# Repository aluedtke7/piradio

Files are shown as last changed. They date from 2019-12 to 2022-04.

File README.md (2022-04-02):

## Internet radio player for the Raspberry PI written in GO

This project describes what is neccessary to build an internet radio player with GO for the Raspberry Pi.
There is a [documentation file](doc/development.md) about some aspects of the software design
(i.e. _why do you use an extra channel for the display?_).

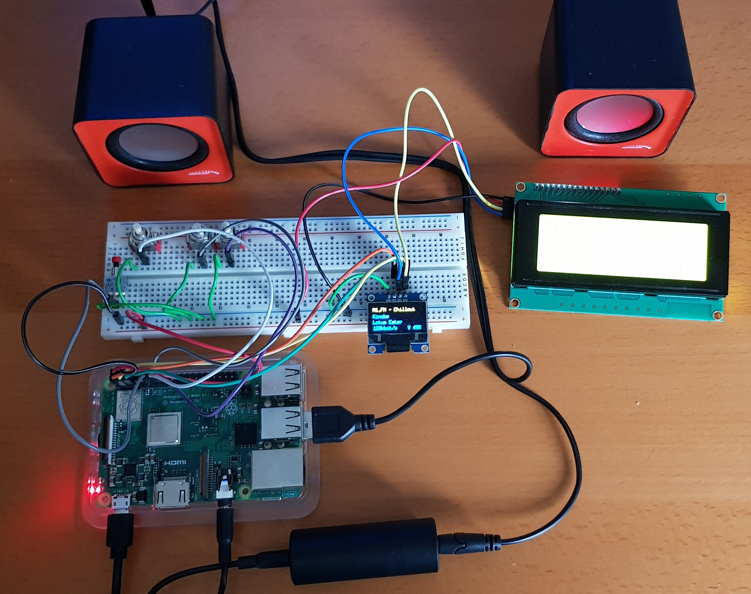
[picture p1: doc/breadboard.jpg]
breadboard


The wiring is also documented with a fritzing sketch.
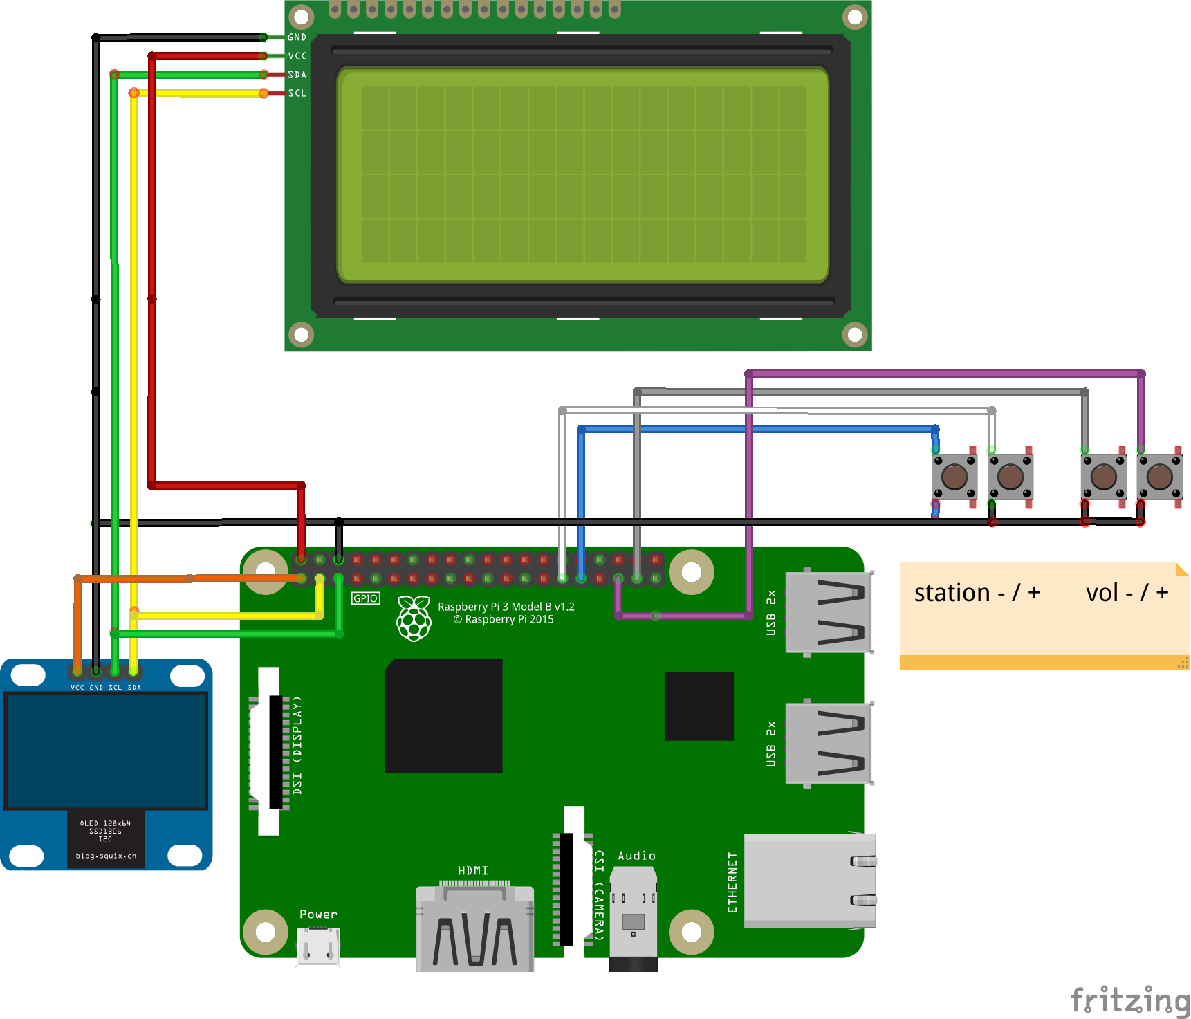
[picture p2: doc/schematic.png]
Fritzing


### Hardware

For the development I'm using a model 3B+ but the final target will be a Raspberry PI Zero WH.
This is the cheapest model that has WIFI. An internet radio without WIFI doesn't makes sense
in my opinion.

The documentation about that version can be found [here](doc/raspi_zero.md).

#### Displays

As display you can choose between two differnt types: a 20x4 LCD or a 0,96" OLED both with i²c interface. The program
can handle both of them but not simultaneously. There's a flag to switch between LCD and OLED (hint try `piradio -help`).

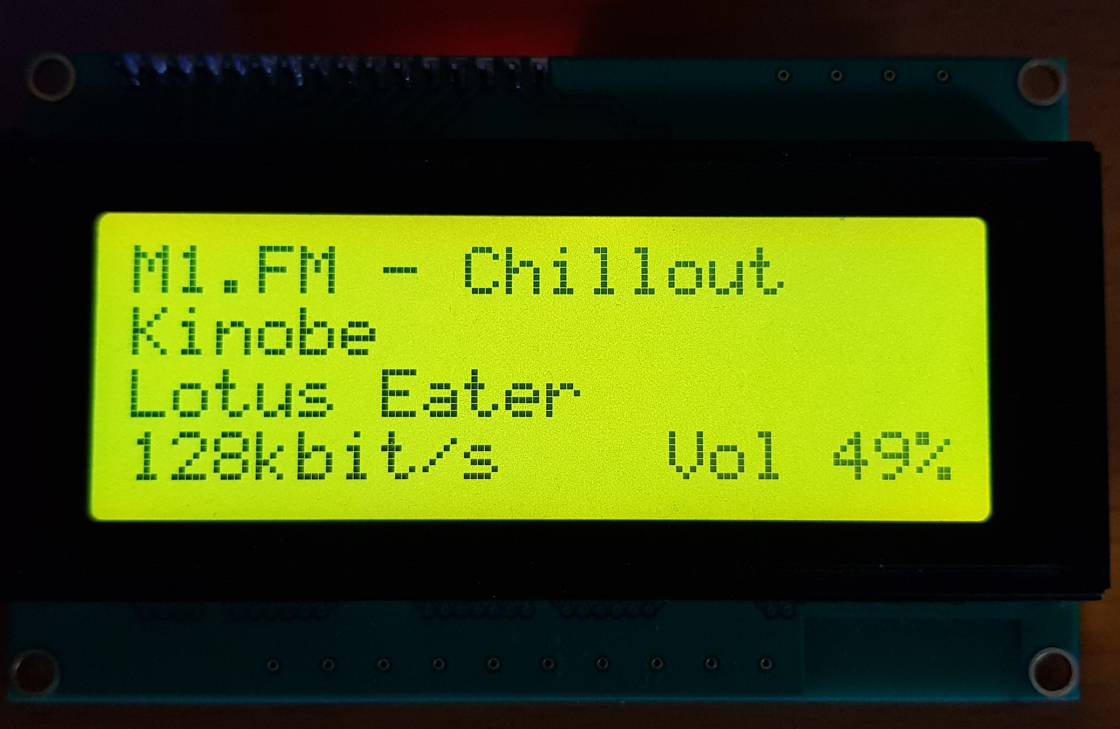
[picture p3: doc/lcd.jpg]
LCD


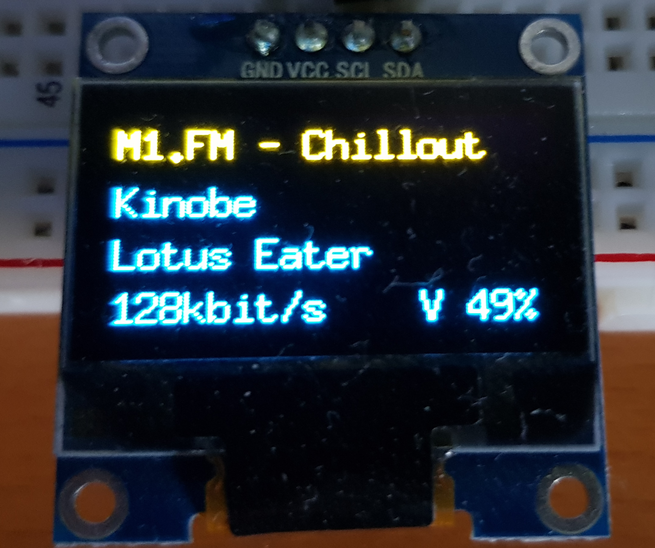
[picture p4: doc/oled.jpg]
OLED


#### Speaker

It's up to you what you use as loudspeakers. I'm using a pair of cheap usb speakers. It's absolutely neccessary to
have a galvanic isolation between the loudspeaker input and the raspberry pi. Otherwise you will hear any possible
interferences in the speakers. I bought the noise filter (ground loop isolator, the black round tube at the bottom of
the photo) from a big american online warehouse.

It's also possible to connect a Bluetooth speaker to the raspberry pi, but that
is documented in the [readme of the Raspi Zero W](doc/raspi_zero.md).

### Software

The software is written in GO (1.18) and it uses the `mplayer` for the heavy lifting part (music streaming etc.).
There are currently 5 (self describing) buttons:

- next station
- previous station
- increase volume
- decrease volume
- mute/unmute

The list of stations is loaded at the start from the location `~/.piradio/stations`. If this file doesn't exist or is
empty, a default list with 3 stations is created. This part was inspired by the
[goradio](https://github.com/jcheng8/goradio) project.

The last played station will be remembered. The actual list index is stored in
`~/.piradio/last_station`. On the next start, the last used station index is loaded. When a station
change is made, the actual index is delayed written to the file (see `debounceWrite`).

The software will always use a 4 line layout on both displays. The LCD can show 20 characters per line and the OLED
is able to show 18,5 characters.
The first line shows always the station name. The second line will display the artist and the title is in the third line.
These two lines automatically scroll in case of long strings. The scroll speed is configurable via flag
`-scrollSpeed`. It's also possible to scroll the station name, but that has to be enabled via flag `-scrollStation`.

The fourth line shows the stream bitrate and the volume level. When the station is changed, the current time and date is
displayed while the next station is loaded. When the first station in the list is selected, the ip address is displayed
instead.

### Preparation of the Raspberry PI

The following paragraphs imply that your raspberry pi is already configured with raspbian and set up in a way that
you can ping him (at 10.7.7.43 in my case) from another pc.

#### enable ssh for login

In file `/etc/ssh/sshd_config` on the raspberry pi change/add the line

    PermitRootLogin yes

Save the file (you probably should use `sudo` for this). After that execute the next two lines

    sudo systemctl start ssh
    sudo systemctl enable ssh

Then execute on the pc

    ssh-copy-id -i ~/.ssh/id_rsa.pub pi@10.7.7.43

This will ensure that you don't need a password for connecting.

On the raspberry pi enter

    sudo passwd

to set a new password for user **root**. After that, enter the following line on the pc:

    ssh-copy-id -i ~/.ssh/id_rsa.pub root@10.7.7.43

This way, you also don't need a password when connecting as user root.

#### Enable i²c

Start program `sudo raspi-config` and select menu `5 Interfacing Options` and there the sub menu
`P5 i²c` via cursors and press ENTER. Move to `<YES>` via cursor keys and press ENTER again.

Restart now the raspberry via `sudo reboot`.
Login and test via tool `i2cdetect` the i²c bus:

    sudo i2cdetect -y 1     # or ...-y 0

This is the output when both displays are connected (LCD is at 27 and OLED is at 3c):

         0  1  2  3  4  5  6  7  8  9  a  b  c  d  e  f
    00:          -- -- -- -- -- -- -- -- -- -- -- -- --
    10: -- -- -- -- -- -- -- -- -- -- -- -- -- -- -- --
    20: -- -- -- -- -- -- -- 27 -- -- -- -- -- -- -- --
    30: -- -- -- -- -- -- -- -- -- -- -- -- 3c -- -- --
    40: -- -- -- -- -- -- -- -- -- -- -- -- -- -- -- --
    50: -- -- -- -- -- -- -- -- -- -- -- -- -- -- -- --
    60: -- -- -- -- -- -- -- -- -- -- -- -- -- -- -- --
    70: -- -- -- -- -- -- -- --

In case the tool is not installed:

    sudo apt update && sudo apt install i2c-tools

#### Start binary with parameters

Piradio comes with several command line parameters. When no parameters are given, the LCD will be used.
All parameters are case sensitive.

    cd /home/pi
    ./piradio           # uses the LCD
    ./piradio -oled     # uses the OLED
    ./piradio -help     # shows all options
    Usage of ./piradio:
      -backlightOff
        	set to switch off backlight after some time
      -backlightOffTime int
        	backlight switch off time in s (3s...3600s) (default 15)
      -camelCase
        	set to format title
      -debug
        	set to output mplayer info on stdout
      -lcdDelay int
        	initial delay for LCD in s (1s...10s) (default 3)
      -noBluetooth
        	set to only use analog output
      -noise
            set to remove noise from title
      -oled
        	set to use OLED Display
      -scrollSpeed int
        	scroll speed in ms (100ms...10000ms) (default 500)
      -scrollStation
        	set to scroll station names

Description of the options:

- backlightOff: if set and if using the LCD, the backlight will be switched off after NN seconds, when no button
  is pressed during this time.
- backlightOffTime: the time in seconds the backlight is on. Will be reset with every button press.
- camelCase: if set, the Title will be formatted in a _camel case_ way
- debug: in case of problems set this option a see what happens on the comand line. `piradio` has to
  be started manually in the shell to see the output.
- lcdDelay: sometimes the LCD will not be correctly initialized and the display shows funny characters.
  In this case increase this value. Only needed for the LCD.
- noBluetooth: when set, no bluetooth connection will be tried.
- noise: some stations transmit very long title names with the remix name in round brackets. If you
  enable this option these strings will be removed and the title will most probably fit on the display without
  scrolling.
- oled: set this option to use the OLED display.
- scrollSpeed: the scrolling is set by default to a speed of 500ms. If this speed is too fast or too
  slow for you, please set a different value here.
- scrollStation: if you want the station name to scroll in case of long names, please enable
  this option.

Various options set:

    ./piradio -oled -camelCase -scrollStation -scrollSpeed=300
    ./piradio -camelCase=false -debug=false -scrollSpeed=300 -scrollStation=false -oled=true
    ./piradio -camelCase=false -debug=false -scrollSpeed=750 -scrollStation=false -lcdDelay=5 -noise=true

### Start piradio on boot

#### Start

In order to start piradio on every boot, we have to add a line in `/etc/rc.local`:

     su pi -c '/home/pi/piradio -oled -scrollSpeed=300 &'

Please put this line **before** the line containing `exit 0`!

This will start `piradio` as a background task of user `pi`. The user switch is needed because otherwise
`piradio` would run with `root` priviliges.

The parameter used are just one possibility to start `piradio` and can also be omitted. It's important
to end the line with an `&` and that the user has the right to start `piradio` in that folder.
The file `rc.local` needs admin rights to be changed:

    sudo nano /etc/rc.local

#### Stop

If you need to stop the automatically started `piradio`, please proceed as follows. First, get the
`Process Group ID (PGID)` of piradio and the mplayer processes:

    ps -o pgid,cmd -U pi

    PGID  CMD
     561  /lib/systemd/systemd --user
     561  (sd-pam)
     570  /home/pi/piradio -oled -scrollSpeed=300
     570  mplayer -quiet http://tuner.m1.fm/chillout.mp3
     570  mplayer -quiet http://tuner.m1.fm/chillout.mp3
     981  sshd: pi@pts/0
     993  -bash
    1044  ps -o pid,ppid,pgid,cmd -U pi

The line containing `/home/pi/piradio ...` has a number (570) in column `PGID`. This PGID number is also
shown in the lines containing `mplayer ...`. To stop all these processes in one go, enter the following:

    kill -- -570

Now you can copy your fresh version of `piradio` to your Raspberry Pi.

### See title/interpret in terminal

If you want to see the actual title/interpret in a remote terminal, you should
run the following command to see the log of piradio:

    less ~/.piradio/log/piradio.pi.INFO

Press `<shift>+<f>` to let less update the log constantly.

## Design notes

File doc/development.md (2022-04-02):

## Development
#### Cross compilation
On your development machine run the following line to build a `piradio` binary that can run on a
raspberry pi:

    GOOS=linux GOARCH=arm go build -o piradio -v piradio.go
    
This will create a binary named `piradio` that can run on an ARM processor running linux.

#### Copy binary to raspberry
If your ssh key is present on the raspberry, you don't need credentials to copy the binary:

    scp piradio pi@10.7.7.43:

or both commands in one go:

    GOOS=linux GOARCH=arm go build -o piradio -v piradio.go && scp piradio pi@10.7.7.43:

#### Run tests
Normally you're developing on a pc. Therefore, the tests will also run on this pc and you have to start
the tests as follows:

    go test piradio.go piradio_test.go -v

Please keep in mind, that you can't test the special raspberry functionalities (GPIO, I²C etc.). 
This can only be tested, if you run them on a raspberry pi with installed GO. See next chapter.

The current tests don't need a raspberry pi and will run on the dev machine without problems.

#### Update all Modules
Run the following command to update all libraries/modules:

    go get -u

#### Install GO on the raspberry
If you don't like cross compilation or if you want to run tests that needs a raspberry pi, you can install
GO directly on the raspberry. Get the golang tar archive from Google:

    curl -L https://dl.google.com/go/go1.13.linux-armv6l.tar.gz -o go1.13.linux-armv6l.tar.gz

Extract the archive:

    sudo tar -C /usr/local -xvf go1.13.linux-armv6l.tar.gz

Test the golang installation:

    go version

## Some thoughts

#### Why a command channel for the display?
The LCD and the OLED package each have a channel that must be used to send data and commands via i²c to the 
display. If we wouldn't use this approach, the commands and data would get mixed up when more than one line 
should display scrolling text. This could lead to a display that doesn't react anymore.

#### Why don't you use WaitForEdge() on the GPIO pins?
This was indeed my first attempt. With that implementation I needed a minimum debounce time of 250ms in order to work 
halfway. Even with this high debounce time I had several double button clicks when I switched through the
stations.

The final implementation works as desired and has a low debounce time of 100ms.

#### Missing artist and/or title
Most probably this behaviour is caused by the radio station. If you are in doubt, please switch the debug mode (-debug) 
on and see for yourself. The output of the mplayer is printed to stdout. The artist/title
information is found in the ICY Info StreamTitle field.
Usually, this field contains the artist and title separated by a hyphen.

Sometimes the StreamTitle field is transported but it's empty.

The other displayed parts (station name and bitrate) might also not be available.
The station name e.g. is transported in the Name field of the stream.

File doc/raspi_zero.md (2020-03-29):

## Preparing the Raspberry Zero W

### Create Micro-SD card
Download the Raspbian Buster Lite image from [this site](https://www.raspberrypi.org/downloads/raspbian/).
Unzip the downloaded file and insert an empty sd card into the card reader.
Check which device is responsible for this card:

    lsblk -p
    
This will give a list with a lot of devices. In my case, the last line showed

    /dev/sdc      8:32   1   3,7G  0 disk

This is the 4GB sd card I'm using. Now enter the following command to copy the image 
to the sd card:

    sudo dd bs=4M if=2019-09-26-raspbian-buster-lite.img of=/dev/sdc status=progress conv=fsync
    
This will take some time. In my case it took 226 seconds. Run `sync` in order to flush
all cached data to the sd card.

### First Boot
Insert the sd card in the sd card slot of the zero w. Connect a display and a keyboard
via the HDMI mini and USB micro connectors and connect the power via the second (right most) 
micro USB connector.

When the login prompt appears, login as user *pi* with password *raspberry* (please mind the English 
keyboard layout).

Run `raspi-config` and select the correct locale, timezone, keyboard layout and wifi country from
menu **4** (Localisation Options). When entering the locale, please select all locales for your country: for German this 
is `de_DE, de_DE.UTF-8 and de_DE@euro`. In menu **2** (Network Options) enter a name for your raspberry.

In order to **not** store the wifi passwords in a human readable way, please proceed as follows
for all wifi networks:

    wpa_passphrase SSID-OF-WIFI SECRET-PASSWORD >> /etc/wpa_supplicant/wpa_supplicant.conf

This tool will add the network settings of the wifi at the end of the given file. Please run

     sudo nano /etc/wpa_supplicant/wpa_supplicant.conf
     
and check the generated part. Remove the commented lines with the unencrypted passwords.

Reboot, login again and try to ping your router.

### Enabling ssh connections and i²c 
Run `raspi-config` and enable *ssh* and *i²c* from menu **5** (Interfacing Options).

Now you can access your Zero W from other computer via `ssh pi@10.7.7.39` i.e. If you want to connect
without entering a password, you have to give your public ssh key to the raspi:

     ssh-copy-id pi@10.7.7.39
     
After done that, you can ssh into your raspi without entering a password.

### Install mplayer
Run `sudo apt update && sudo apt install mplayer`.

#### Enable i²c
Start program `sudo raspi-config` and select menu `5 Interfacing Options` and there the sub menu
`P5 i²c` via cursors and press ENTER. Move to `<YES>` via cursor keys and press ENTER again.

Restart now the raspberry via `sudo reboot`.
Login and test via tool `i2cdetect` the i²c bus:

    sudo i2cdetect -y 1     # or ...-y 0
    
This is the output when both displays are connected (LCD is at 27 and OLED is at 3c):

         0  1  2  3  4  5  6  7  8  9  a  b  c  d  e  f
    00:          -- -- -- -- -- -- -- -- -- -- -- -- -- 
    10: -- -- -- -- -- -- -- -- -- -- -- -- -- -- -- -- 
    20: -- -- -- -- -- -- -- 27 -- -- -- -- -- -- -- -- 
    30: -- -- -- -- -- -- -- -- -- -- -- -- 3c -- -- -- 
    40: -- -- -- -- -- -- -- -- -- -- -- -- -- -- -- -- 
    50: -- -- -- -- -- -- -- -- -- -- -- -- -- -- -- -- 
    60: -- -- -- -- -- -- -- -- -- -- -- -- -- -- -- -- 
    70: -- -- -- -- -- -- -- --                         

In case the tool is not installed:

    sudo apt update && sudo apt install i2c-tools

### Updating all packages
Run `sudo apt update && sudo apt upgrade` and wait until all updates are installed.

### Audio output
Since the Raspberry Zero dowsn't have an audio jack, we need to route the internal
PWM signals to GPIO pins and shape the signal so that they are compatible with standard
audio equipment. The routing is done with an entry in `/boot/config.txt`. Just put the 
following line at the end of the file:

    dtoverlay=pwm-2chan,pin=18,func=2,pin2=13,func2=4

You need su rights to change the file. After changing, please reboot.

#### Signal shaping
The shaping is a simple RC lowpass filter together with an output condensator to eliminate
dc from the signal. Since the pwm output have a quite high voltage, a voltage divider is
in front of the filter. The calculation for the RC filter was done on [this page](https://electronicbase.net/de/tiefpass-berechnen/#passiver-tiefpass-1-ordnung).
The Fritzing schematic is located in [this file](https://github.com/aluedtke7/piradio/blob/master/doc/RaspiZero.fzz).

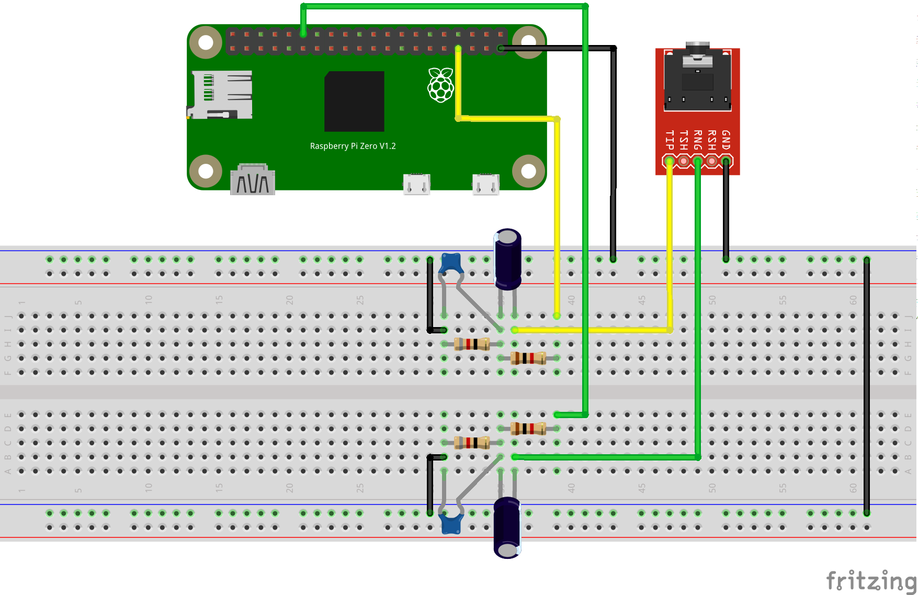
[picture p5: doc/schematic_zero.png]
Fritzing Zero


### Stream to a bluetooth speaker
If you don't want to use the 3.5mm jack as audio source, then you can use a bluetooth speaker, but
that needs some preparation.

First you have to install 2 packages:

    sudo apt update && sudo apt install pulseaudio pulseaudio-module-bluetooth
    
Next, you have to enable the user `pi` to use the `bluetothctl` tool. Therefore, the following
code has to be placed in the file `/etc/dbus-1/system.d/bluetooth.conf`. You need superuser rights
for that:
````
  <policy user="pi">
    <allow send_destination="org.bluez"/>
    <allow send_interface="org.bluez.Agent1"/>
    <allow send_interface="org.bluez.GattCharacteristic1"/>
    <allow send_interface="org.bluez.GattDescriptor1"/>
    <allow send_interface="org.freedesktop.DBus.ObjectManager"/>
    <allow send_interface="org.freedesktop.DBus.Properties"/>
  </policy>
````
The policy must be placed inside of tag `<busconfig>`.

Now the speaker has to be paired with the raspi. Start `bluetoothctl` and enter the following
commands. The tool `bluetoothctl` should already be installed on your Zero W:

    power on
    agent on
    default-agent

Now start the bluetooth scan. Before that, you should switch your bt speaker into the pairing mode.

    scan on
    
After several seconds, your speaker should be listed with the address and name. Remember the address.
Now stop the scan with `scan off` and pair, trust and connect the speaker. Please replace the
xx:xx:xx:xx:xx:xx with the real address of your speaker:

    pair xx:xx:xx:xx:xx:xx
    trust xx:xx:xx:xx:xx:xx
    connect xx:xx:xx:xx:xx:xx
    
With the last command you should hear a tone from your speaker that the connection was successful.

Now you should leave bluetoothctl via `exit` or `<ctrl>+<d>`. If you now start piradio, mplayer should
automatically pick up the bluetooth connection for playing audio. If piradio is already started,
just change the station and mplayer will be started with a different streaming url and uses bluetooth.
    
### Power supply
I decided to buy a cheap power bank pcb, because that gave me the most possibilities. The pcb I bought has
2 USB type A outputs and a micro USB Input for charging. In addition, it has a small LCD that shows
the current percentage of capacity. On the side there's a small push button that handles on and off
switching. The battery is a LiPo of size 18650.

Power bank pcb:
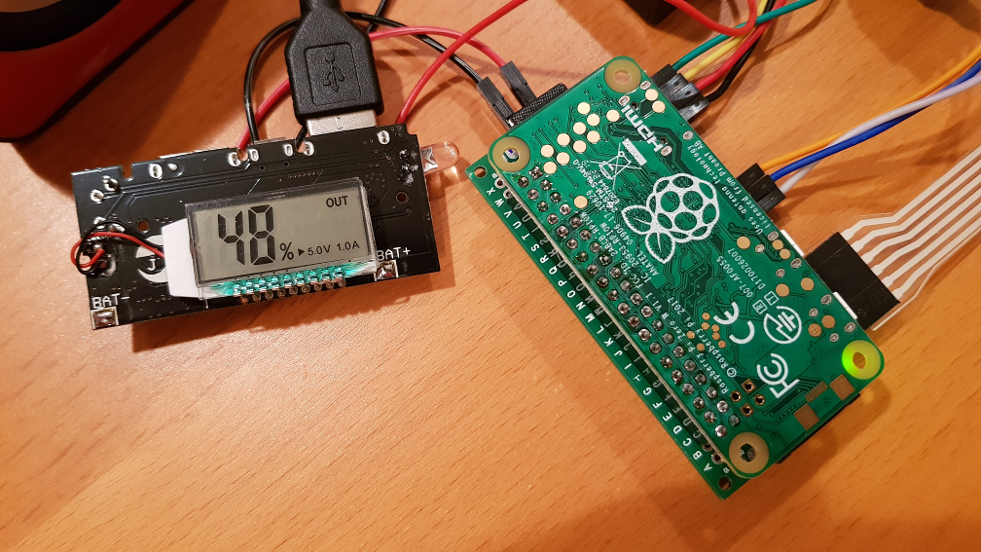
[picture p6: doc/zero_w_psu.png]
power supply


### More photos
All together:
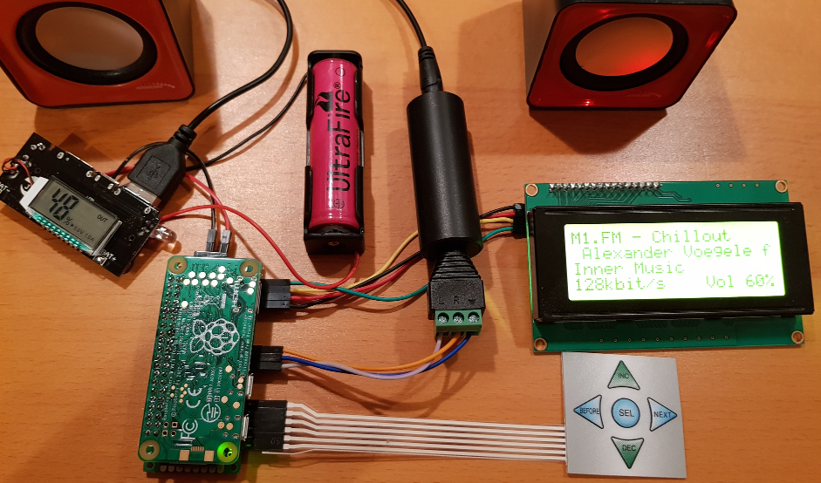
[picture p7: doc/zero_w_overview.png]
all together


Keypad:
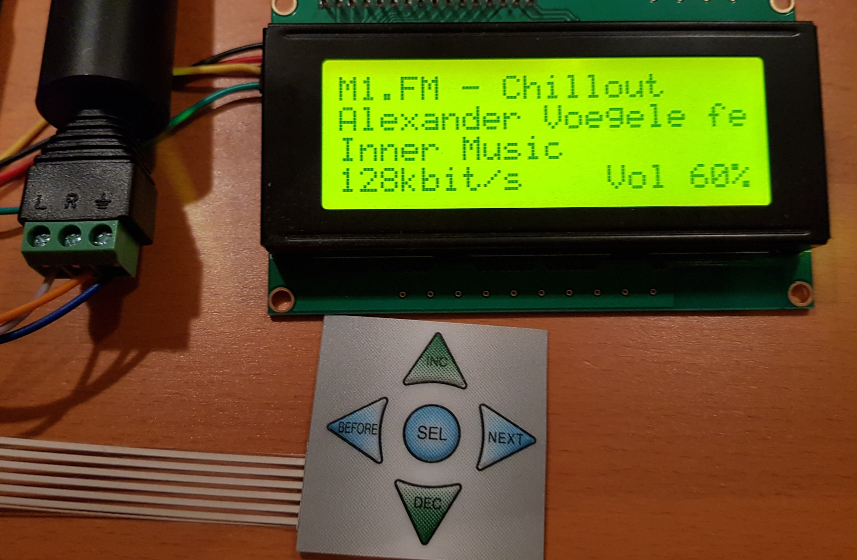
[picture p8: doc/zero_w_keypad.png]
keypad


Filter/connector board:
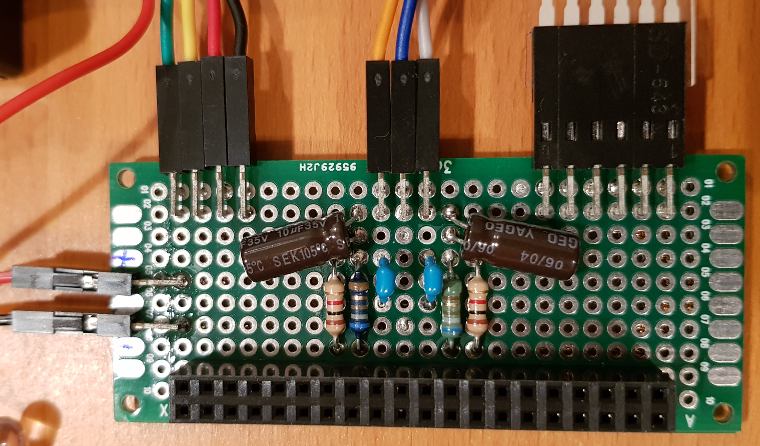
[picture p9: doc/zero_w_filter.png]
board1


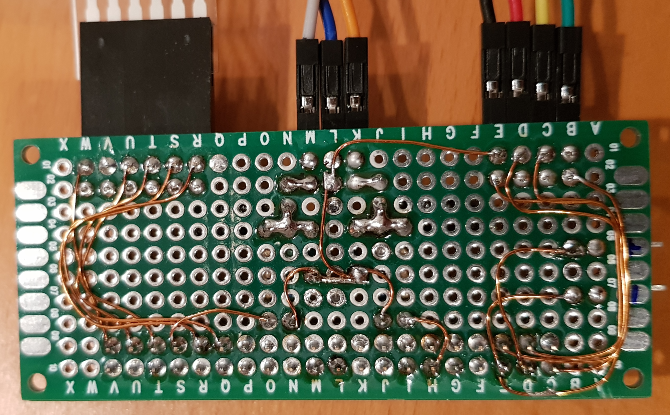
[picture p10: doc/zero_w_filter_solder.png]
board2


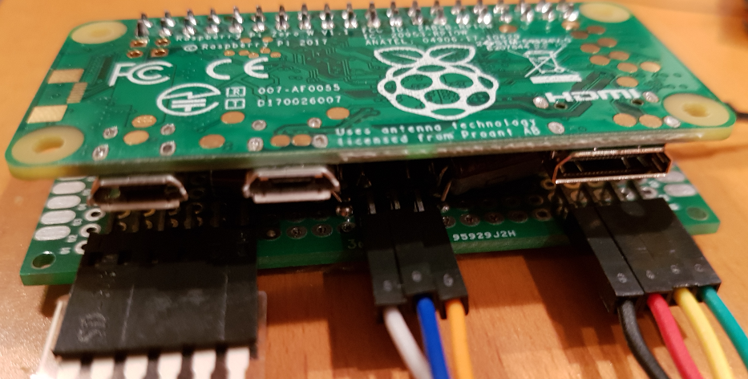
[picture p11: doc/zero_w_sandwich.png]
board3


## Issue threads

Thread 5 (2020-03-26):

Wrong volume level after mode switch

aluedtke7, 2020-03-26:
When a bluetooth speaker is connected, the mplayer is started again with the same parameters in order to use the bt speaker.
Sometimes the volume level is not shown at all and sometimes it's too low.

Closed 2020-03-29.

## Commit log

2019-12-01 first official version
    [Raspi3.fzz]
2020-01-03 new doc file for raspberry zero w
2020-03-08 Raspberry Zero fritzing, GPIO pins for buttons changed
    [Raspi3.fzz, RaspiZero.fzz]
2020-03-18 Raspberry Zero doc completed, pictures added
2020-03-28 Backlight can be switched off after some time, switch for not using bluetooth
2020-03-30 log typo fixed, noise removal of 'cut', test added
